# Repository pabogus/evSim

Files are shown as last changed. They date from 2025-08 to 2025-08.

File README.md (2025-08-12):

# Project evSim 
## Purpose description
Simulate a ev connected to a Wallbox for testing purposes.

For testing the behaviour of a AC walbox, respecively charging station, for e-mobility a car simulator is needed.
This project aims to provide such a simulator. In addition for test automation this simulator can be controlled via modbus protocoll using a RS485 connection.
You should be aware about the ISO states and the underlying physical protocoll used on the CS and PP line of a type-2 conector.

The project uses a attiny1616 controller to switch a couple of relays to simulate the voltage levels on the signal lines.
The relais are driven by a TPIC6B595 shift register which has the capability to drive the relays.
The RS485 lines are driven by a MAX 485 ECSA transmitter. The PWM is injected via an optocoppler  LTV 817B.

## As user interface there are:
Two buttons to switch states and cable attributes
An OLED display for the states and the measured PWM duty cycle
ws2812 like LED stripe also to indicate states and PWM duty cycle, respectively the current level.

## Schematic and PCB:
The project contains also a schematic and a PCB in KiCad format with the following features:
The evSim contains also an additional FET incl. a flyback diode, to drive an external releay, e.g. to switch the Walbox on and off.
The evSim provides an additional input at the plug connector intended for current on check.
The evSim contains two simulatior entities to be able to test a twin wallbox.
The evSim contains a voltage regulator for 5V to be independant of the power supply.
The evSim contains a coding switch for the modbus-ID.

For connection screw connectors are used.

### Note:
Currently this is done as a prototype and for usage in a real test environment the following improvements could be done.
- Add some more Cs or Ls for hardening against radiation and spikes.
- Add bigger voltage regulator, or use a tree pin DC/DC converter.
- Make PCB a bit larger, avoid SMD on the backside, add proper conector for power, Modbus and additional functions.

## Not tested/implemented yet:
Additional FET
Selection of modbus-ID via coding switch. Idea is to double use some GPIO lines and read the input at start-up.
Some supporting modbus registers.
Read in voltage on phase L1 with FinA/FinB, just with an opto and capacitive devider to be able to check that the walbox has realy turned on power. (But caution here you touch high volate, I would place the opto and devider on a separate small PCB)

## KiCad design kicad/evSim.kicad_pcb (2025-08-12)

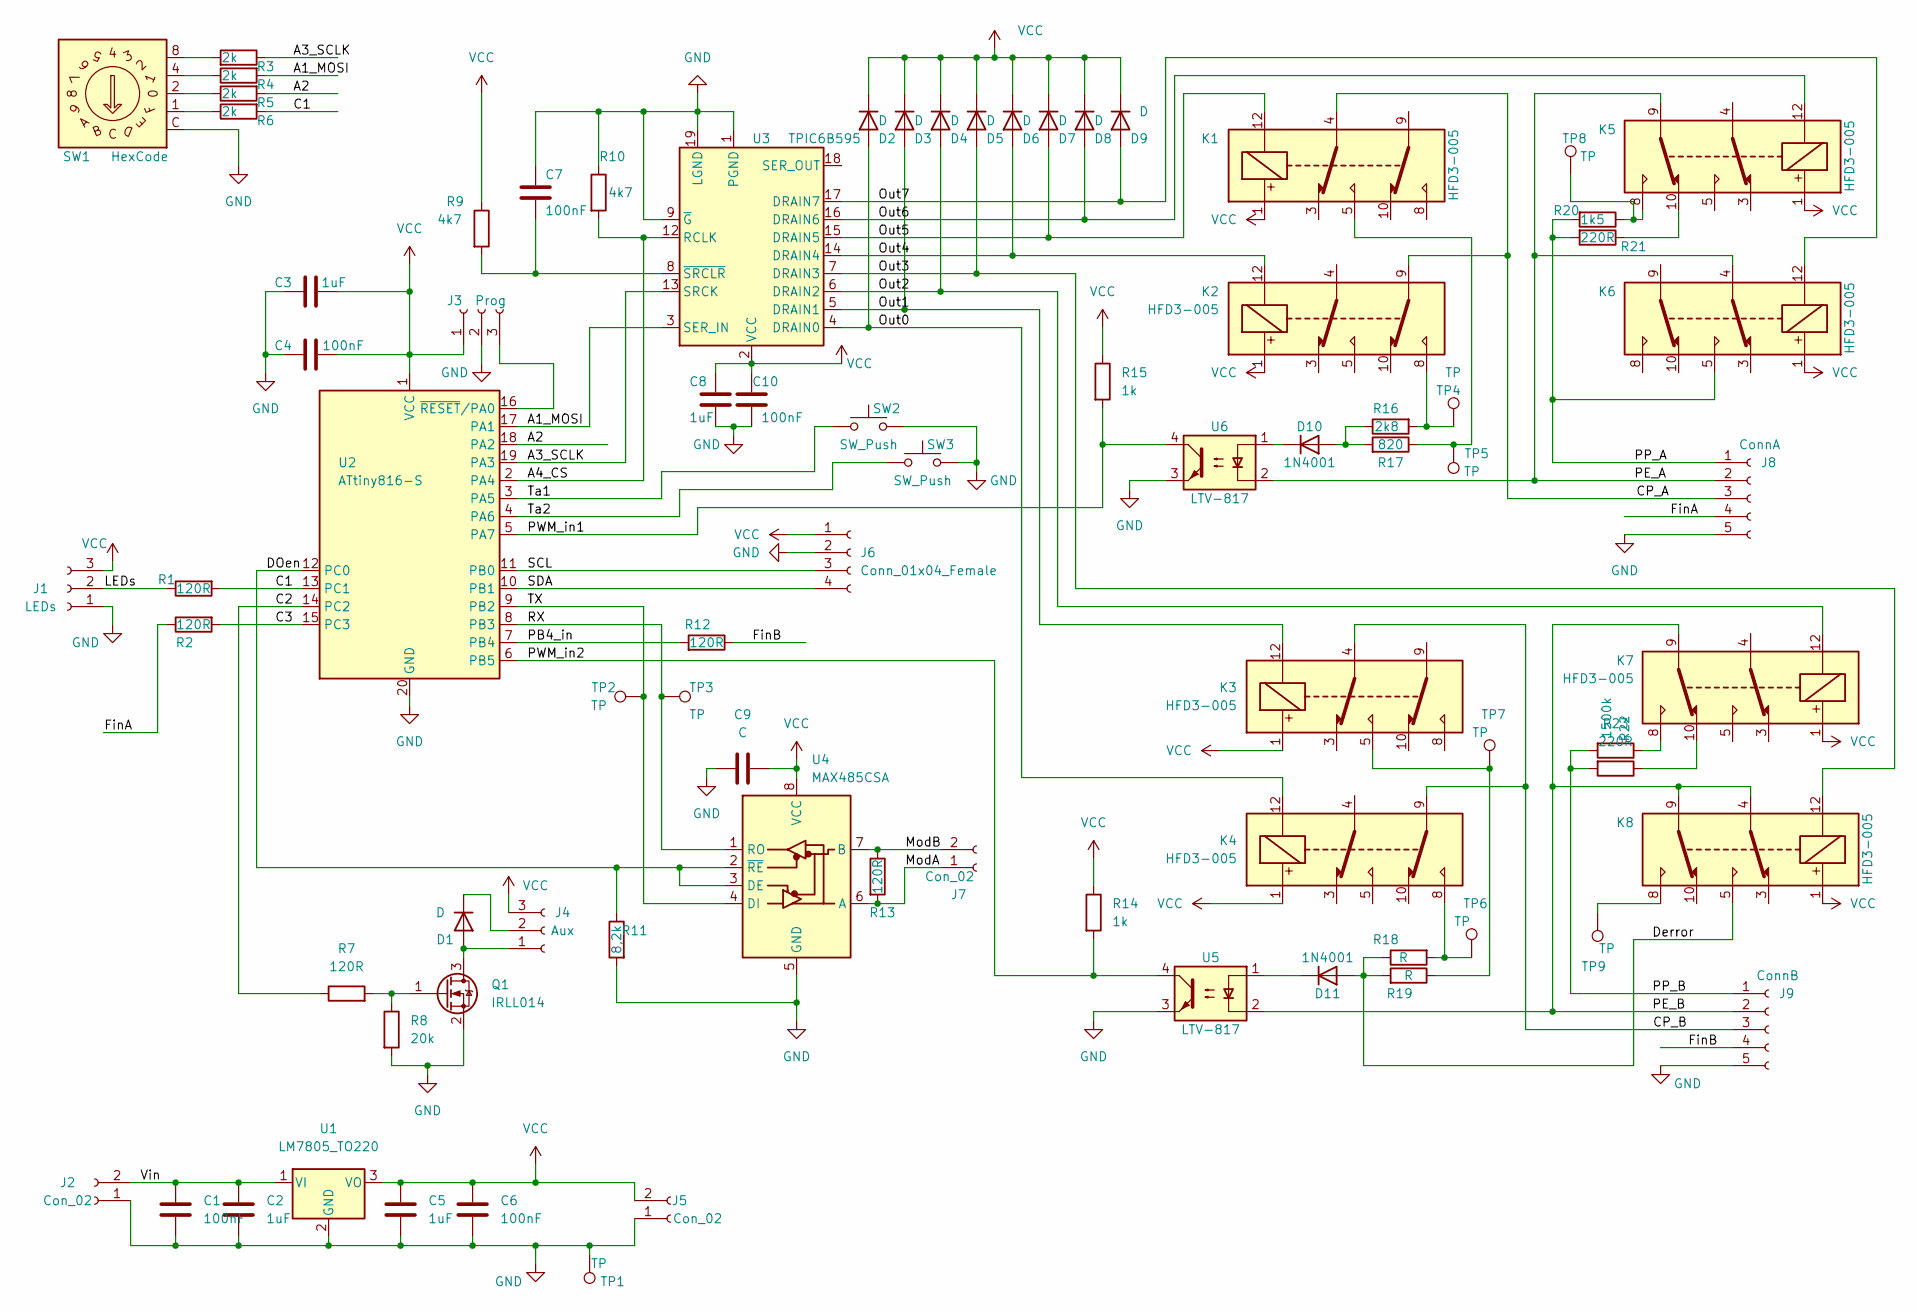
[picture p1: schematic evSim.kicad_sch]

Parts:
C1, C4, C7, C10: 100nF; C_0805_2012Metric_Pad1.18x1.45mm_HandSolder
C2, C5, C8: 1uF; C_0805_2012Metric_Pad1.18x1.45mm_HandSolder
C3: 1uF; C_Disc_D4.7mm_W2.5mm_P5.00mm
C6: 100nF; C_1206_3216Metric_Pad1.33x1.80mm_HandSolder
C9: C; C_0805_2012Metric_Pad1.18x1.45mm_HandSolder
D1: D; D_SMA_Handsoldering
D2, D3, D4, D5, D6, D7, D8, D9: D; D_A-405_P5.08mm_Vertical_AnodeUp
D10, D11: 1N4001; D_A-405_P2.54mm_Vertical_AnodeUp
J1: LEDs; PinHeader_1x03_P2.54mm_Vertical
J2, J5, J7: Con_02; PinHeader_1x02_P2.54mm_Vertical
J3: Prog; PinHeader_1x03_P2.54mm_Vertical
J4: Aux; PinHeader_1x03_P2.54mm_Vertical
J6: Conn_01x04_Female; PinHeader_1x04_P2.54mm_Vertical
J8: ConnA; PhoenixContact_MCV_1,5_5-G-5.08_1x05_P5.08mm_Vertical
J9: ConnB; PhoenixContact_MCV_1,5_5-G-5.08_1x05_P5.08mm_Vertical
K1, K2, K3, K4, K5, K6, K7, K8: HFD3-005; Relay_DPDT_Kemet_EC2
Q1: IRLL014; SOT-23
R1, R2, R7, R12: 120R; R_1206_3216Metric_Pad1.30x1.75mm_HandSolder
R3, R4, R5, R6: 2k; R_1206_3216Metric_Pad1.30x1.75mm_HandSolder
R8: 20k; R_1206_3216Metric_Pad1.30x1.75mm_HandSolder
R9, R10: 4k7; R_1206_3216Metric_Pad1.30x1.75mm_HandSolder
R11: 8,2k; R_1206_3216Metric_Pad1.30x1.75mm_HandSolder
R13: 120R; R_Axial_DIN0207_L6.3mm_D2.5mm_P7.62mm_Horizontal
R14, R15: 1k; R_1206_3216Metric_Pad1.30x1.75mm_HandSolder
R16: 2k8; R_Axial_DIN0207_L6.3mm_D2.5mm_P7.62mm_Horizontal
R17: 820; R_Axial_DIN0207_L6.3mm_D2.5mm_P7.62mm_Horizontal
R18, R19: R; R_Axial_DIN0207_L6.3mm_D2.5mm_P7.62mm_Horizontal
R20: 1k5; R_Axial_DIN0207_L6.3mm_D2.5mm_P7.62mm_Horizontal
R21, R23: 220R; R_Axial_DIN0207_L6.3mm_D2.5mm_P7.62mm_Horizontal
R22: 1500k; R_Axial_DIN0207_L6.3mm_D2.5mm_P7.62mm_Horizontal
SW1: HexCode; Nidec_Copal_SH-7010C
SW2, SW3: SW_Push; SW_SPST_B3S-1000
TP1, TP4, TP5, TP6, TP7, TP8, TP9: TP; TestPoint_Keystone_5000-5004_Miniature
TP2, TP3: TP; TestPoint_Pad_1.0x1.0mm
U1: LM7805_TO220; TO-252-3_TabPin2
U2: ATtiny816-S; SOIC-20W_7.5x12.8mm_P1.27mm
U3: TPIC6B595; DIP-20_W7.62mm
U4: MAX485CSA; SO-8_3.9x4.9mm_P1.27mm
U5, U6: LTV-817; DIP-4_W7.62mm

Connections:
/A1_MOSI: R4.2, U2.17 (PA1), U3.3 (SER_IN)
/A2: R5.2, U2.18 (PA2)
/A3_SCLK: R3.1, U2.19 (PA3), U3.13 (SRCK)
/A4_CS: R10.2, U2.2 (PA4), U3.12 (RCLK)
/C1: R1.2, R6.2, U2.13 (PC1)
/C2: R7.1, U2.14 (PC2)
/C3: R2.2, U2.15 (PC3)
/CP_A: J8.3, K1.4, K2.9
/CP_B: J9.3, K3.4, K4.9
/DOen: R11.1, U2.12 (PC0), U4.2 (~RE), U4.3 (DE)
/Derror: D11.2 (A), K8.5, R18.1, R19.2
/FinA: J8.4, R2.1
/FinB: J9.4, R12.1
/LEDs: J1.2, R1.1
/ModA: J7.1, R13.2, U4.6 (A)
/ModB: J7.2, R13.1, U4.7 (B)
/Out0: D2.2 (A), K4.12, U3.4 (DRAIN0)
/Out1: D3.2 (A), K3.12, U3.5 (DRAIN1)
/Out2: D4.2 (A), K7.12, U3.6 (DRAIN2)
/Out3: D5.2 (A), K8.12, U3.7 (DRAIN3)
/Out4: D6.2 (A), K2.12, U3.14 (DRAIN4)
/Out5: D7.2 (A), K1.12, U3.15 (DRAIN5)
/Out6: D8.2 (A), K5.12, U3.16 (DRAIN6)
/Out7: D9.2 (A), K6.12, U3.17 (DRAIN7)
/PB4_in: R12.2, U2.7 (PB4)
/PE_A: J8.2, K5.9, K6.4, U6.2
/PE_B: J9.2, K7.9, K8.4, K8.9, U5.2
/PP_A: J8.1, K6.5, R20.2, R21.2
/PP_B: J9.1, R22.2, R23.2
/PWM_in1: R15.2, U2.5 (PA7), U6.4
/PWM_in2: R14.2, U2.6 (PB5), U5.4
/RX: TP3.1, U2.8 (PB3), U4.1 (RO)
/SCL: J6.3, U2.11 (PB0)
/SDA: J6.4, U2.10 (PB1)
/TX: TP2.1, U2.9 (PB2), U4.4 (DI)
/Ta1: SW2.1, U2.3 (PA5)
/Ta2: SW3.1, U2.4 (PA6)
/Vin: C1.1, C2.1, J2.2, U1.1 (VI)
GND: C1.2, C2.2, C3.1, C4.1, C5.2, C6.2, C7.1, C8.2, C9.1, C10.2, J1.1, J2.1, J3.2, J5.1, J6.2, J8.5, J9.5, Q1.2 (S), R8.2, R10.1, R11.2, SW1.C, SW2.2, SW3.2, TP1.1, U1.2 (GND), U2.20 (GND), U3.1 (PGND), U3.9 (~G), U3.10 (PGND), U3.11 (PGND), U3.19 (LGND), U3.20 (PGND), U4.5 (GND), U5.3, U6.3
unnamed: D1.2 (A), J4.1, Q1.3 (D)
unnamed: D1.1 (K), J4.2
unnamed: D10.2 (A), R16.1, R17.2
unnamed: D10.1 (K), U6.1
unnamed: D11.1 (K), U5.1
unnamed: J3.3, U2.16 (~RESET/PA0)
unnamed: K1.5, R17.1, TP5.1
unnamed: K2.8, R16.2, TP4.1
unnamed: K3.5, R19.1, TP7.1
unnamed: K4.8, R18.2, TP6.1
unnamed: K5.8, R20.1, TP8.1
unnamed: K5.10, R21.1
unnamed: K7.8, R22.1
unnamed: K7.10, R23.1
unnamed: K8.8, TP9.1
unnamed: Q1.1 (G), R7.2, R8.1
unnamed: R3.2, SW1.8
unnamed: R4.1, SW1.4
unnamed: R5.1, SW1.2
unnamed: R6.1, SW1.1
unnamed: C7.2, R9.2, U3.8 (~SRCLR)
VCC: C3.2, C4.2, C5.1, C6.1, C8.1, C9.2, C10.1, D2.1 (K), D3.1 (K), D4.1 (K), D5.1 (K), D6.1 (K), D7.1 (K), D8.1 (K), D9.1 (K), J1.3, J3.1, J4.3, J5.2, J6.1, K1.1, K2.1, K3.1, K4.1, K5.1, K6.1, K7.1, K8.1, R9.1, R14.1, R15.1, U1.3 (VO), U2.1 (VCC), U3.2 (VCC), U4.8 (VCC)

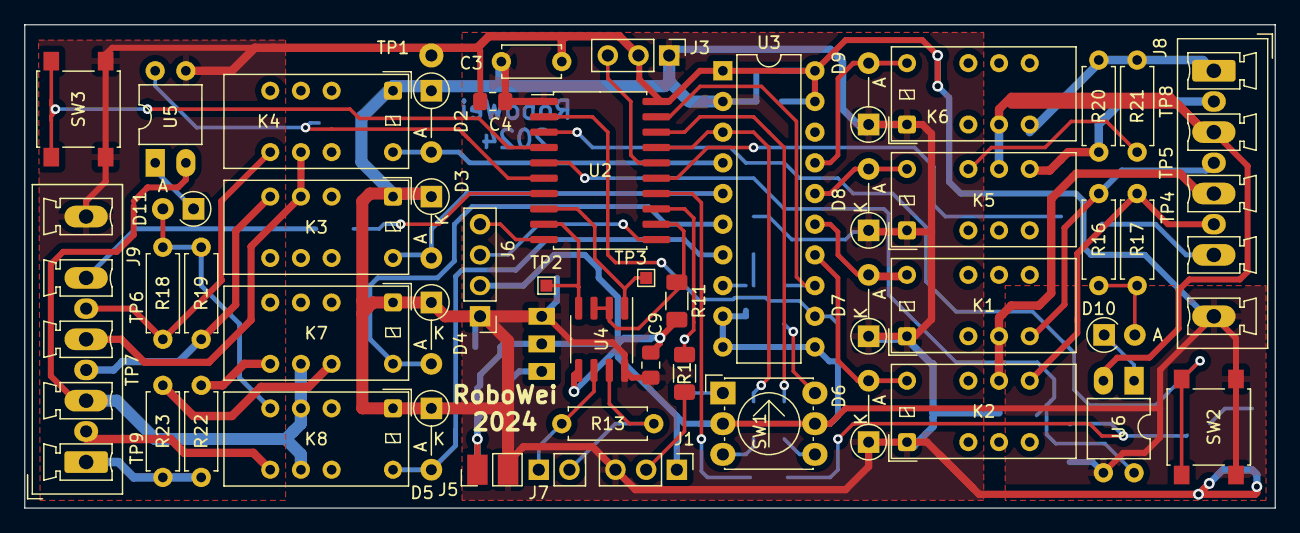
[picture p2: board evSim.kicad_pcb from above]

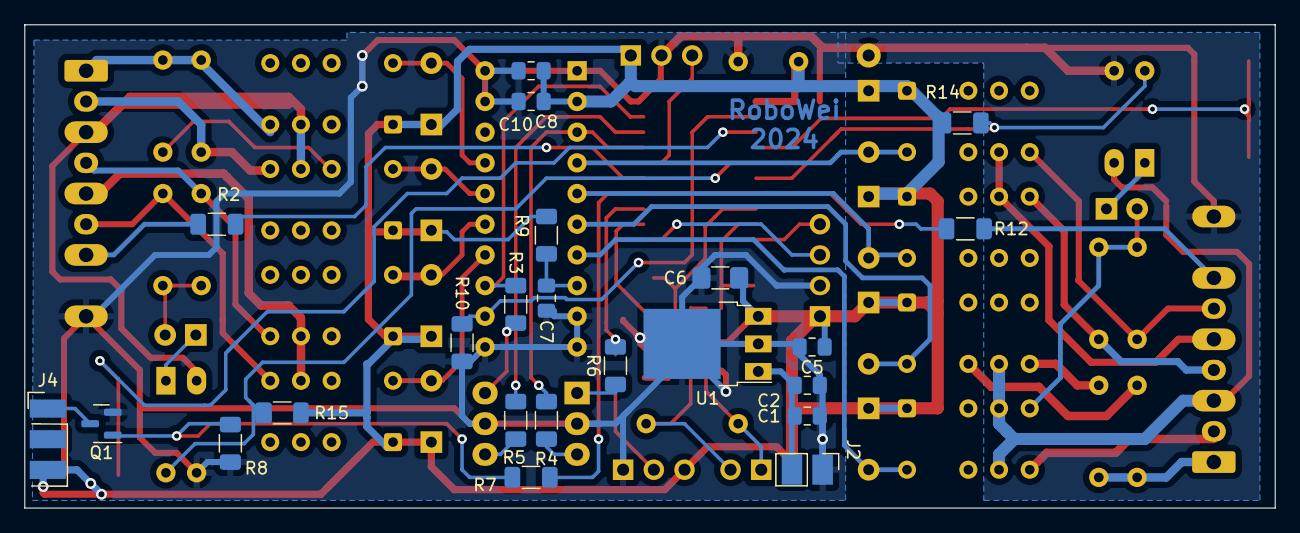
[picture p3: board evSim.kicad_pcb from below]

Board: 2 copper layers, 103.5 x 40.0 mm, 79 parts (23 on the bottom side), 60 nets.

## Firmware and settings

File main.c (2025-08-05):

/*
 * This file is part of evSim
 *
 * Copyright (C) 2025 pabogus <https://github.com/pabogus>
 *
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
 * You should have received a copy of the GNU Affero General Public License
 * along with this program. If not, see <https://www.gnu.org/licenses/>.
 */

/*
 * main.c
 *
 * Contains main() and the functions to switch output for relais to realice
 * the evse states signaled via CP and CS as well as functions to measure the 
 * duty cycle of the PWM provided by the outlet controller.
 *
 * History
 * 28.12.2023 Initial version
 *       2024 Review and corrections
 * 02.08.2025 Beatyfiing for upload to GitHub
 * 
 */

/* Notes and infos:

Commandlines to flash used under Linux:
---------------------------------------
avrdude -c xplainedmini_updi -F -C $ATMEL_DIR/avrdude.conf -p t1616 -U flash:v:main.hex
~/.local/bin/pyupdi -c /dev/ttyUSB0 -d tiny826 -f main.hex
pymcuprog write -d t1616 -t uart -u /dev/ttyUSB0 --erase --verify -f main.hex


Commandline examples to use mbpoll to issue modbus RTU messages under Linux
For testing this dongle was used:
<https://www.reichelt.de/de/de/shop/produkt/raspberry_pi_-_usb-rs485-schnittstelle_ch340c-242783>
-----------------------------------------------------
mbpoll -v -m rtu  -a 2 -b 9600 -t 4 /dev/ttyUSB0 0xA

Set ISO State A, B and C
mbpoll -v -m rtu  -a 2  -b 9600 -t 4 -1 /dev/ttyUSB0 0xa
mbpoll -v -m rtu  -a 2  -b 9600 -t 4 -1 /dev/ttyUSB0 0xb
mbpoll -v -m rtu  -a 2  -b 9600 -t 4 -1 /dev/ttyUSB0 0xc

Read ISO State B
mbpoll -v -m rtu  -a 2 -r 3 -b 9600 -t 4 -1 /dev/ttyUSB0

Read all States
mbpoll -v -m rtu  -a 2 -c 4 -b 9600 -t 4 -1 /dev/ttyUSB0

Read PWM and inputs
mbpoll -v -m rtu  -a 2 -c 5 -b 9600 -t 3:hex -1 /dev/ttyUSB0

Set & Read configuration
mbpoll -v -m rtu  -a 2 -r 11 -c 5 -b 9600 -t 4 -1 /dev/ttyUSB0
mbpoll -v -m rtu  -a 2 -r 11  -b 9600 -t 4 /dev/ttyUSB0 48
mbpoll -v -m rtu  -a 2 -r 12  -b 9600 -t 4 /dev/ttyUSB0 3

Read SW infos
mbpoll -v -m rtu  -a 2 -r 11 -c 5 -b 9600 -t 3:hex -1 /dev/ttyUSB0

Read PWM A
mbpoll -v -m rtu  -a 2  -b 9600 -t 3 -1 /dev/ttyUSB0

Read PWM A & PWM P
mbpoll -v -m rtu  -a 2 -c 2  -b 9600 -t 3 -1 /dev/ttyUSB0

Read configuration
mbpoll -v -m rtu  -a 2  -b 9600 -t 4 -1 /dev/ttyUSB0

*/


/* Pinout informationn

Testbuild / breadboard setup: 

             AtTiny1616
                _____
            Vcc-|   |-Gnd
      CS -- PA4-|   |-PA3 --SCLK
    TA_A -- PA5-|   |-PA2 --
    TA_B -- PA6-|   |-PA1 --MOSI
   PWM_A -- PA7-|   |-Reset/UPDI
   PWM_B --´PB5-|   |-PC3 --
         -- PB4-|   |-PC2 --
     RxD -- PB3-|   |-PC1 --LEDs
     TxD -- PB2-|   |-PC0 --RXen
     SDA -- PB1-|   |-PB0 --SCL
                -----

PCB setup: 
             AtTiny1616
                _____
            Vcc-|   |-Gnd
      CS -- PA4-|   |-PA3 --SCLK
    TA_A -- PA5-|   |-PA2 --
    TA_B -- PA6-|   |-PA1 --MOSI
   PWM_A -- PA7-|   |-Reset/UPDI
   PWM_B --´PB5-|   |-PC3 --Fin_A
   Fin_B -- PB4-|   |-PC2 --Aux_FET
     RxD -- PB3-|   |-PC1 --LEDs
     TxD -- PB2-|   |-PC0 --RXen
     SDA -- PB1-|   |-PB0 --SCL
                -----


              TPIC6B595N
                _____
             NC-|   |-NC
            VCC-|   |-Gnd
   MOSI --  Sin-|   |-Sout
        -- Out0-|   |-Out7 --ISO_B_1
        -- Out1-|   |-Out6 --ISO_C_1
        -- Out2-|   |-Out5 --MODE_13_A_1
        -- Out3-|   |-Out4 --MODE_ERROR
VCC/Cap -- /Clr-|   |-SCLK --SCLK
    GND --  /G -|   |-RCLK -CS
            GND-|   |-GND
                -----
*/


#include <avr/io.h>
#include <util/delay.h>
#include <string.h>
#include <avr/interrupt.h>
#include <avr/pgmspace.h>
#include "config.h"
#include "spi_func.h"
#include "I2C_func.h"
#include "oled1306.h"
#include "key_func.h"
#include "support_lib.h"
#include "rs232.h"
#include "modbusRtu_func.h"
#include "led_ws2812.h"
#include "evSim.h"


/**************************************************************
 * HW Setup configuration
 * ***********************************************************/
#define REL_BIT_ISO_B_1 4
#define REL_BIT_ISO_C_1 5
#define REL_BIT_13_A_1 6
#define REL_BIT_ERR_1 7

#define REL_BIT_ISO_B_2 0
#define REL_BIT_ISO_C_2 1
#define REL_BIT_13_A_2 2
#define REL_BIT_ERR_2 3

#define SERIAL_PORT_CS_PIN 4
#define RELAIS_CS_PORT PORTA_OUT

#define AUX_PORT_PIN 2
#define AUX_PORT PORTC_OUT


#define CFG_DEFAULT_BRIGHTNESS 48
#define LONG_PRESSED_CNT 50


char string[20];


void IOinit(void)
{
  PORTA.PIN7CTRL = PORT_INVEN_bm;    // Invert input

  PORTA.PIN5CTRL = PORT_PULLUPEN_bm; // Enable Pullup for PA5
  PORTA.PIN6CTRL = PORT_PULLUPEN_bm; // Enable Pullup for PA6
}

/**************************************************************
 * Modbus related functions
 * ***********************************************************/
void init_modbus_registers(void)
{
  // Read/Write -> Func 0x06 / 0x16
  analogOutput[AO_REG_OFFSET_ISO_A] = REGVALUE_ISOSTATE_A;
  analogOutput[AO_REG_OFFSET_MOD_A] = REGVAL_MODE_MAX;
  analogOutput[AO_REG_OFFSET_ISO_B] = REGVALUE_ISOSTATE_A;
  analogOutput[AO_REG_OFFSET_MOD_B] = REGVAL_MODE_MAX;

  analogOutput[AO_REG_OFFSET_CFG_BRIGHTNESS] = CFG_DEFAULT_BRIGHTNESS;
  
  // Set the default orientation of the display as defined in config.h
  // For testing the other options can be commented in.
  analogOutput[AO_REG_OFFSET_CFG_ROTATION] = CFG_DEFAULT_ROTATION;
//  analogOutput[AO_REG_OFFSET_CFG_ROTATION] = ROTATION_HORIZONTAL;
//  analogOutput[AO_REG_OFFSET_CFG_ROTATION] = ROTATION_HORIZONTAL_FLIP;
//  analogOutput[AO_REG_OFFSET_CFG_ROTATION] = ROTATION_VERTICAL;
//  analogOutput[AO_REG_OFFSET_CFG_ROTATION] = ROTATION_VERTICAL_FLIP;



  // Read Only  ->
  // TODO set on real build date
  analogInput[AI_REG_OFFSET_SW_VERSION] = 0x0101;
  analogInput[AI_REG_OFFSET_SW_YEAR] = 0x2024;
  analogInput[AI_REG_OFFSET_SW_MONTHDAY] = 0x0116;
}


/**************************************************************
 * Timer PWM/Freq capture setup and handling
 * ***********************************************************/

volatile uint16_t PWM0_high = 0;
volatile uint16_t PWM0_dur = 0;
ISR(TCB0_INT_vect)
{
  PWM0_dur = TCB0.CNT;
  PWM0_high = TCB0.CCMP;
}

volatile uint16_t PWM1_high = 0;
volatile uint16_t PWM1_dur = 0;
ISR(TCB1_INT_vect)
{
  PWM1_dur = TCB1.CNT;
  PWM1_high = TCB1.CCMP;
}

void EVENT_SYSTEM_init(void)
{
  EVSYS.ASYNCUSER0 = EVSYS_ASYNCUSER0_ASYNCCH0_gc;
  EVSYS.ASYNCCH0 = EVSYS_ASYNCCH0_PORTA_PIN7_gc;

  EVSYS.ASYNCUSER11 = EVSYS_ASYNCUSER11_ASYNCCH1_gc;
  EVSYS.ASYNCCH1 = EVSYS_ASYNCCH1_PORTB_PIN5_gc;
}

void TCB_init(void)
{
  /* 3,33MHz Prescaler 1 > 0,3 us > 1kHz => 3333 Ticks
     3,33MHz Prescaler 2 > 0,6 us > 1kHz => 1666 Ticks
     10  MHz Prescaler 1 > 0,1 us > 1kHz => 10000 Ticks
     10  MHz Prescaler 2 > 0,2 us > 1kHz => 5000 Ticks
     20  MHz Prescaler 1 > 0,05us > 1kHz => 20000 Ticks
     20  MHz Prescaler 2 > 0,1 us > 1kHz => 10000 Ticks
   */
  TCB0.CTRLB = TCB_CNTMODE_FRQPW_gc; // Input capture pulse width measurement and frequency
  TCB0.EVCTRL = TCB_CAPTEI_bm;       // Enable the timer capture interrupt
  TCB0.INTCTRL = TCB_CAPT_bm;        // Enable the Capture Interrupt
  TCB0.CTRLA = TCB_ENABLE_bm;        // Select Pre scaler //Start Timmer

  TCB1.CTRLB = TCB_CNTMODE_FRQPW_gc; // Input capture pulse width measurement and frequency
  TCB1.EVCTRL = TCB_CAPTEI_bm;       // Enable the timer capture interrupt
  TCB1.INTCTRL = TCB_CAPT_bm;        // Enable the Capture Interrupt
  TCB1.CTRLA = TCB_ENABLE_bm;        // Select Pre scaler //Start Timmer
}

/**************************************************************
 * Calculation
 * ***********************************************************/

uint8_t dutyCycle_1(void)
{
  uint16_t tmp16;
  uint16_t val16;
  if (PWM0_dur == 0)
  {
    if (PORTA_IN & _BV(7))
      return 100;
    else
      return 0;
  }
  tmp16 = PWM0_dur / 100;
  val16 = PWM0_high / tmp16;
  PWM0_dur = 0;
  return val16;
}

uint8_t dutyCycle_2(void)
{
  uint16_t tmp16;
  uint16_t val16;
  if (PWM1_dur == 0)
  {
    if (PORTB_IN & _BV(5))
      return 100;
    else
      return 0;
  }
  tmp16 = PWM1_dur / 100;
  val16 = PWM1_high / tmp16;
  PWM1_dur = 0;
  return val16;
}


/**************************************************************
 * Switch pins and relays on shift register via SPI
 * ***********************************************************/

uint8_t serial_port = 0;
void set_serial_port(uint8_t pattern)
{
  PORTA_OUT = PORTA_OUT & ~_BV(SERIAL_PORT_CS_PIN);
  SPI0_exchangeData(pattern);
  PORTA_OUT = PORTA_OUT | _BV(SERIAL_PORT_CS_PIN);
  serial_port = pattern;
}

void set_serial_port_pin(uint8_t pin, uint8_t state)
{
  if (state)
    serial_port = serial_port | (1<<pin);
  else
    serial_port = serial_port & ~(1<<pin);
  set_serial_port(serial_port);
}

void set_relais_A(void)
{
  uint8_t iso;
  uint8_t mode;

  iso  = analogOutput[AO_REG_OFFSET_ISO_A];
  mode = analogOutput[AO_REG_OFFSET_MOD_A];

  serial_port = serial_port &
    ~(_BV(REL_BIT_ISO_B_1) | _BV(REL_BIT_ISO_C_1) | _BV(REL_BIT_13_A_1) | _BV(REL_BIT_ERR_1));

  switch (iso)
  {
    case REGVALUE_ISOSTATE_C:
      serial_port = serial_port | _BV(REL_BIT_ISO_C_1);
      break;
    case REGVALUE_ISOSTATE_1B:
    case REGVALUE_ISOSTATE_B:
      serial_port = serial_port | _BV(REL_BIT_ISO_B_1);
      break;
  }
  switch (mode)
  {
    case REGVAL_MODE_13A:
      serial_port = serial_port | _BV(REL_BIT_13_A_1);
      break;
    case REGVAL_MODE_ERR:
      serial_port = serial_port | _BV(REL_BIT_ERR_1);
      break;
  }
  set_serial_port(serial_port);
}

void set_relais_B(void)
{
  uint8_t iso;
  uint8_t mode;

  iso  = analogOutput[AO_REG_OFFSET_ISO_B];
  mode = analogOutput[AO_REG_OFFSET_MOD_B];

  serial_port = serial_port &
    ~(_BV(REL_BIT_ISO_B_2) | _BV(REL_BIT_ISO_C_2) | _BV(REL_BIT_13_A_2) | _BV(REL_BIT_ERR_2));

  switch(iso)
  {
    case REGVALUE_ISOSTATE_C:
      serial_port = serial_port | _BV(REL_BIT_ISO_C_2);
      break;
    case REGVALUE_ISOSTATE_1B:
    case REGVALUE_ISOSTATE_B:
      serial_port = serial_port | _BV(REL_BIT_ISO_B_2);
      break;
  }
  switch(mode)
  {
    case REGVAL_MODE_13A:
      serial_port = serial_port | _BV(REL_BIT_13_A_2);
      break;
    case REGVAL_MODE_ERR:
      serial_port = serial_port | _BV(REL_BIT_ERR_2);
      break;
  }
  set_serial_port(serial_port);
}


/**************************************************************
 * Show state information via a small array of ws2812 compatible 
 * LEDs. 
 * ***********************************************************/

pixel_array_t pixel_array[NR_OF_LEDS_ON_STRIP] = {0};
uint8_t pixel_data[NR_OF_LEDS_ON_STRIP] = {0};

// There are 10 LEDs with the following meaning: 
#define LED_ISO_A  0
#define LED_MOD_A  1
#define LED_PWM1_A 2
#define LED_PWM2_A 3
#define LED_PWM3_A 4
#define LED_ISO_B  5
#define LED_MOD_B  6
#define LED_PWM1_B 7
#define LED_PWM2_B 8
#define LED_PWM3_B 9

/* Three LEDs will be used to indicate the PWM duty cycle, 
   respectively the output current. The levels are according to
   specification. 

https://de.wikipedia.org/wiki/IEC_62196_Typ_2
Pulsweiten zur Anzeige der höchsten Stromlast[7] PWM 	SAE dauerhaft 	SAE kurzzeitig 	IEC 61851-1
97 %	80 A (EU)   1 White  LED
95 %	77,5 A (EU) 3 Violet LEDs
90 %	65 A (EU)   2 Violet LEDs
85 %	51 A (EU)   1 Violet LED
80 %	48 A (EU)   3 Red    LEDs
70 %	42 A (EU)   2 Red    LEDs
60 %	36 A (EU)   1 Red    LED
50 % 	30 A (EU)   2 Orange LEDs
40 % 	24 A (EU)   2 Orange LEDs
30 % 	18 A (EU)   1 Orange LED
25 % 	15 A (EU)   3 Yellow LED
16 %	9,6 A (EU)  2 Yellow LEDs
10 %	6 A (EU)    1 Yellow LED
                      OFF

Following colors are used for the ISO states and cable mode

ISO_A Green
ISO_B Cyan
ISO_C Blue

MODE_MAX Off
MODE_13A Magenta
MODE_ERR Red
*/

void set_led_array(uint8_t select)
{
  uint8_t iso;
  uint8_t mode;
  uint8_t offset;
  uint8_t brightness = get_AO_register_lo(AO_REG_OFFSET_CFG_BRIGHTNESS);

  if (SELECT_A == select)
  {
    iso  = analogOutput[AO_REG_OFFSET_ISO_A];
    mode = analogOutput[AO_REG_OFFSET_MOD_A];
    offset = 0;
  }
  else
  {
    iso  = analogOutput[AO_REG_OFFSET_ISO_B];
    mode = analogOutput[AO_REG_OFFSET_MOD_B];
    offset = LED_ISO_B;
  }

  switch (iso)
  {
    case REGVALUE_ISOSTATE_C:
      pixel_array[offset + LED_ISO_A].pixel = hsv_to_rgb(H_VAL_BLUE, 255, brightness);
      break;
    case REGVALUE_ISOSTATE_1B:
    case REGVALUE_ISOSTATE_B:
      pixel_array[offset + LED_ISO_A].pixel = hsv_to_rgb(H_VAL_BLUE_GREEN, 255, brightness/2);
      break;
    default:
      pixel_array[offset + LED_ISO_A].pixel = hsv_to_rgb(H_VAL_GREEN, 255, brightness);
      break;
  }
  switch (mode)
  {
    case REGVAL_MODE_13A:
      pixel_array[offset + LED_MOD_A].pixel = hsv_to_rgb(H_VAL_YELLOW_GREEN, 255, brightness);
      break;
    case REGVAL_MODE_ERR:
      pixel_array[offset + LED_MOD_A].pixel = hsv_to_rgb(H_VAL_RED, 255, brightness);
      break;
    default:
      pixel_array[offset + LED_MOD_A].pixel = hsv_to_rgb(0, 0, 0);
      break;
  }
}

void set_leds_color(pixel_array_t* leds, uint8_t nr, uint8_t h, uint8_t s, uint8_t v)
{
  while (nr--)
  {
    leds[2].pixel = hsv_to_rgb(h, s, v);
  }
}

void set_3_leds(pixel_array_t* leds, uint8_t nr, uint8_t bg_h, uint8_t bg_brightness, uint8_t set_h)
{
  uint8_t brightness = get_AO_register_lo(AO_REG_OFFSET_CFG_BRIGHTNESS);
  for(uint8_t n = 0; n < 3; n++)
    leds[n].pixel = hsv_to_rgb(bg_h, 255, bg_brightness);
  if (nr > 0)
    leds[0].pixel = hsv_to_rgb(set_h, 255, brightness);
  if (nr > 1)
    leds[1].pixel = hsv_to_rgb(set_h, 255, brightness);
  if (nr > 2)
    leds[2].pixel = hsv_to_rgb(set_h, 255, brightness);
}


/* Remember above :-)
97 %	80 A (EU)   1 White
95 %	77,5 A (EU) 3 Violet
90 %	65 A (EU)   2 Violet
85 %	51 A (EU)   1 Violet
80 %	48 A (EU)   3 Red
70 %	42 A (EU)   2 Red
60 %	36 A (EU)   1 Red
50 % 	30 A (EU)   2 Orange
40 % 	24 A (EU)   2 Orange
30 % 	18 A (EU)   1 Orange
25 % 	15 A (EU)   3 Yellow
16 %	9,6 A (EU)  2 Yellow
10 %	6 A (EU)    1 Yellow
                    OFF
*/

void set_led_array_pwm(pixel_array_t* leds, uint8_t dc)
{
  uint8_t brightness = get_AO_register_lo(AO_REG_OFFSET_CFG_BRIGHTNESS);
  if (dc == 100)
  {
    leds[0].pixel = hsv_to_rgb(0, 0, 0);
    leds[1].pixel = hsv_to_rgb(0, 0, 0);
    leds[2].pixel = hsv_to_rgb(H_VAL_RED, 0, brightness);
  }
  else if (dc >= 97) set_3_leds(leds, 3, H_VAL_VIOLET, brightness, H_VAL_INDIGO);
  else if (dc >= 90) set_3_leds(leds, 2, H_VAL_VIOLET, brightness, H_VAL_INDIGO);
  else if (dc >= 85) set_3_leds(leds, 1, H_VAL_VIOLET, brightness, H_VAL_INDIGO);
  else if (dc >= 80) set_3_leds(leds, 3, H_VAL_RED, brightness, H_VAL_VIOLET);
  else if (dc >= 70) set_3_leds(leds, 2, H_VAL_RED, brightness, H_VAL_VIOLET);
  else if (dc >= 60) set_3_leds(leds, 1, H_VAL_RED, brightness, H_VAL_VIOLET);
  else if (dc >= 50) set_3_leds(leds, 3, H_VAL_YELLOW, brightness, H_VAL_RED);
  else if (dc >= 40) set_3_leds(leds, 2, H_VAL_YELLOW, brightness, H_VAL_RED);
  else if (dc >= 30) set_3_leds(leds, 1, H_VAL_YELLOW, brightness, H_VAL_RED);
  else if (dc >= 25) set_3_leds(leds, 3, H_VAL_GREEN, 0, H_VAL_YELLOW);
  else if (dc >= 16) set_3_leds(leds, 2, H_VAL_GREEN, 0, H_VAL_YELLOW);
  else if (dc >= 10) set_3_leds(leds, 1, H_VAL_GREEN, 0, H_VAL_YELLOW);
  else set_3_leds(leds, 0, H_VAL_GREEN, 0, H_VAL_YELLOW);
}

void update_leds(uint8_t update)
{
  uint8_t dc;
  if (update & UPDATE_STATE_A)
    set_led_array(SELECT_A);
  if (update & UPDATE_STATE_B)
    set_led_array(SELECT_B);
  dc = get_AI_register_lo(AI_REG_OFFSET_PWM_A);
  if (update & UPDATE_PWM_A)
    set_led_array_pwm(&pixel_array[2], dc);
  dc = get_AI_register_lo(AI_REG_OFFSET_PWM_B);
  if (update & UPDATE_PWM_B)
    set_led_array_pwm(&pixel_array[7], dc);
}


/**************************************************************
 * Initialization and main loop
 * ***********************************************************/
int main(void)
{
//  uint8_t h,s,v;
//  uint8_t tmp;
  uint16_t tmp16;
  uint16_t val16;
  uint8_t update;

  CPU_CCP = 0xD8;
  CLKCTRL_MCLKCTRLB = 0x1; /* divider 2 Clock = 10MHz => one Tick = 100ns*/

  IOinit();

  SPI0_init_master(SPI_PRESC_DIV64_gc, 0);
  set_serial_port(0);

  I2C_init_master(I2C_BAUD_100kHz);
  _delay_ms(100);

  oled_init(OLED_DISP_ON);
  _delay_ms(100);
  oled_gotoxy(0,0); oled_putc(65);
  oled_gotoxy(1,1); oled_putc(66);
  oled_gotoxy(2,2); oled_putc(67);
  _delay_ms(1000);

  while (0)
  {
    PORTA_OUT = PORTA_OUT & ~_BV(SERIAL_PORT_CS_PIN);
    SPI0_exchangeData(0xaa);
    PORTA_OUT = PORTA_OUT | _BV(SERIAL_PORT_CS_PIN);
    _delay_ms(100);

    PORTA_OUT = PORTA_OUT & ~_BV(SERIAL_PORT_CS_PIN);
    SPI0_exchangeData(0x55);
    PORTA_OUT = PORTA_OUT | _BV(SERIAL_PORT_CS_PIN);
    _delay_ms(100);
  }

  while (0)
  {
    set_serial_port_pin(7, 1);
    _delay_ms(200);
    set_serial_port_pin(6, 1);
    _delay_ms(200);
    set_serial_port_pin(5, 1);
    _delay_ms(200);
    set_serial_port_pin(4, 1);
    _delay_ms(200);
    set_serial_port(0);
    _delay_ms(200);
  }
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

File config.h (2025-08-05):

#ifndef _CONFIG_H_
#define _CONFIG_H_

/*
 * config.h
 *
 * Created: 30.12.2023
 * Author:  Robert Weikert
 */

#include <avr/io.h>
#include <util/delay.h>
#include <string.h>
#include <avr/interrupt.h>
#include <avr/pgmspace.h>


/*
//--------------------------------------------------------------------
// configure USART Settings
//--------------------------------------------------------------------
*/
#define USE_UART
// Must be power of 2
#define UART_RX_BUFFER_LEN 64
//#define UART_MAX_LINE_LENGTH 16
#define USART_USE_RX_INTERRUPT
//#define USART_USE_RX_INTERRUPT_ECHO
//#define uart_rx_idx GPIOR1
#define RESET_TIMEOUT TCA0_SINGLE_CNT=0

/*
//--------------------------------------------------------------------
// configure modbus RTU functions
//--------------------------------------------------------------------
*/
// #define NR_OF_AO_REGISTERS 16
// #define NR_OF_AI_REGISTERS 16
#define RTU_TIMOUT_COUNTER TCA0_SINGLE_CNT


/*
//--------------------------------------------------------------------
// configure I2C
//--------------------------------------------------------------------
*/
#define USE_I2C_MASTER


/*
//--------------------------------------------------------------------
// configure oled functions
//--------------------------------------------------------------------
*/
#define SH1106	// or SSD1306, check datasheet of your display
//#define SSD1306
//#define SSD1306_64x48
//#define USE_OLED_FONT_6x8
#define USE_OLED_FONT_8x16
//#define USE_OLED_GRAPHIC_SUPPORT
#define USE_OLED_VERTICAL
#define OLED_FLIP_HORIZONTAL

#define CFG_DEFAULT_ROTATION ROTATION_VERTICAL_FLIP
//#define CFG_DEFAULT_ROTATION ROTATION_HORIZONTAL_FLIP


/*
//--------------------------------------------------------------------
// configure support functions
//--------------------------------------------------------------------
*/

//#define USE_BIT_TO_STR_FUNCTION
#define USE_U_TO_STR_FUNCTION
//#define USE_I_TO_STR_FUNCTION
//#define USE_DISPLAY_BUFFER
//#define SIZE_OF_DISPLAY_BUFFER 40


/*
//--------------------------------------------------------------------
// configure led_ws2812
//--------------------------------------------------------------------
*/
#define LED_VPORT_OUT VPORTC_OUT
#define LED_STIPE_DATA_PIN_NR 1
#define USE_FAST_HSV2RGB_FUNCTION
//#define LED_DIM_NR_SHIFTS 4


/*
//--------------------------------------------------------------------
// configure LED Strip functions
//--------------------------------------------------------------------
*/
#define DEFAULT_BRIGTNES 128
#define NR_OF_LEDS_ON_STRIP 20


//--------------------------------------------------------------------
// Configuration for key input functions
// Place needed defines into config.h
//--------------------------------------------------------------------
#define _ENABLE_SIMPLE_KEY_INPUT
#define TASTER1_PORT_IN PORTA_IN
#define TASTER1_PIN 5
//#define TASTER2_PORT_IN PORTA_IN
//#define TASTER2_PIN 2
//#define TASTER3_PORT_IN PORTA_IN
//#define TASTER3_PIN 3
//#define TASTER4_PORT_IN PORTA_IN
//#define TASTER4_PIN 4
//#define TASTER5_PORT_IN PORTA_IN
//#define TASTER5_PIN 5

//#define ENABLE_ADC_KEY_INPUT
//#define TASTER_ADCIN ADC_MUXPOS_AIN2_gc

#endif // _CONFIG_H_

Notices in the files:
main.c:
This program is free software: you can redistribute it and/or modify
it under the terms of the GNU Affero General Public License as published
